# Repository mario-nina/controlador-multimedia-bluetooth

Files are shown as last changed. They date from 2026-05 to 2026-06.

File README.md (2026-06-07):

# Controlador Multimedia Bluetooth






Controlador multimedia inalámbrico portátil basado en ESP32 que permite gestionar la reproducción de audio en una computadora mediante comunicación Bluetooth.

---

## Tabla de contenidos

- [Descripción](#descripción)
- [Características](#características)
- [Requisitos](#requisitos)
- [Instalación](#instalación)
- [Uso](#uso)
- [Estructura del proyecto](#estructura-del-proyecto)
- [Hardware](#hardware)
- [Firmware](#firmware)
- [Documentación](#documentación)
- [Versionado](#versionado)
- [Licencia](#licencia)
- [Autor](#autor)

---

## Descripción

El sistema permite controlar remotamente la reproducción multimedia de una laptop sin requerir interacción física directa con la misma. Comunica mediante protocolo Bluetooth HID, lo que garantiza compatibilidad nativa con el sistema operativo sin necesidad de software adicional.

Desarrollado como proyecto de la materia Sistemas Embebidos II de la carrera de Ingeniería Mecatrónica en la Universidad Católica Boliviana.

---

## Características

- Control de reproducción: Play/Pause
- Navegación entre pistas: Siguiente y Anterior
- Control de volumen: Incremento y Decremento
- Silenciamiento: Mute/Unmute
- Comunicación inalámbrica mediante Bluetooth HID
- Operación autónoma mediante batería Li-ion recargable
- Indicadores visuales de estado de conexión y batería
- Gestión energética con modem sleep y escalado dinámico de frecuencia CPU

---

## Requisitos

### Hardware

| Componente | Especificación |
|---|---|
| Microcontrolador | ESP32 WROOM-32 (DevKit 30 pines) |
| Batería | Li-ion 18650 3.7V 2600mAh |
| Módulo de carga | TP4056 USB-C con protección |
| Boost converter | MT3608 |
| Regulador | AMS1117-3.3V |
| Encoder rotativo | Alps EC11 |
| Botones | 3 pulsadores táctiles |
| Indicadores | LED azul (Bluetooth — GPIO32), LED rojo (batería — GPIO33) |

### Software

| Herramienta | Versión |
|---|---|
| ESP-IDF | v6.0.1 |
| KiCad | 8.0 |
| Sistema operativo | Ubuntu 24.04 LTS |
| Compilador | xtensa-esp-elf-gcc 15.2.0 |
| Python | 3.12.3 |
| CMake | 3.28.3 |
| Git | 2.43.0 |

---

## Instalación

### Configuración del entorno

1. Instalar ESP-IDF v6.0.1 siguiendo la [documentación oficial](https://docs.espressif.com/projects/esp-idf/en/stable/esp32/get-started/index.html).

2. Clonar el repositorio:
```bash
git clone git@github.com:mario-nina/controlador-multimedia-bluetooth.git
cd controlador-multimedia-bluetooth
```

3. Activar el entorno ESP-IDF:
```bash
get_idf
```

4. Configurar el chip objetivo:
```bash
cd firmware
idf.py set-target esp32
```

5. Compilar el firmware:
```bash
idf.py build
```

6. Flashear el ESP32:
```bash
idf.py flash monitor
```

---

## Uso

1. Encender el dispositivo.
2. En la laptop, activar Bluetooth y buscar dispositivos disponibles.
3. Emparejar con el dispositivo **"Controlador Multimedia"**.
4. Una vez conectado, usar los controles:

| Control | Función |
|---|---|
| Encoder — girar derecha | Subir volumen |
| Encoder — girar izquierda | Bajar volumen |
| Encoder — presionar | Play/Pause |
| Botón 1 | Siguiente pista |
| Botón 2 | Pista anterior |
| Botón 3 | Mute/Unmute |

### Indicadores visuales

| LED | Estado | Significado |
|-----|---|---|
| Azul | Parpadeo rápido | Sin conexión BLE — advertising |
| Azul | Apagado | Conexión BLE activa |
| Rojo | Apagado | Batería OK (>= 3400mV) |
| Rojo | Parpadeo lento | Batería baja (< 3400mV) |
| Rojo | Parpadeo rápido | Batería crítica (< 3200mV) |

---

## Estructura del proyecto
controlador-multimedia-bluetooth/
├── firmware/                          # Código fuente del firmware (ESP-IDF)
│   ├── main/                          # Punto de entrada de la aplicación
│   │   └── firmware.c
│   └── components/                    # Módulos independientes
│       ├── common/                    # Configuración global del sistema
│       │   └── include/
│       │       ├── config.h           # Constantes de configuración del sistema
│       │       └── pines.h            # Mapa de asignación de pines GPIO
│       ├── comunicacion_bt/           # Stack NimBLE + perfil HID Consumer Control
│       ├── control_leds/              # Patrones de LEDs via esp_timer
│       ├── driver_entrada/            # Botones (ISR) + encoder rotativo (PCNT)
│       └── gestion_energia/           # Monitoreo ADC batería + modem sleep
├── hardware/                          # Archivos de diseño de hardware
│   ├── kicad/                         # Proyecto KiCad (esquemático + PCB)
│   ├── exportaciones/                 # Archivos exportados desde KiCad
│   │   ├── esquematico/               # PDF y SVG del esquemático
│   │   ├── gerbers/                   # Archivos Gerber para fabricación
│   │   └── step/                      # Modelos 3D de la carcasa
│   └── pines.md                       # Asignación de pines con justificación técnica
├── docs/                              # Documentación técnica
│   ├── memoria_tecnica/               # Memoria técnica del proyecto (entrega académica)
│   ├── diseno_pcb.md                  # Decisiones de diseño PCB con justificación
│   ├── manual_usuario/                # Manual de usuario
│   └── lista_materiales/             # Lista de materiales con especificaciones y costos
├── test/                              # Pruebas y validación
│   └── resultados/                    # Resultados de pruebas documentadas
├── CHANGELOG.md
├── CONTRIBUTING.md
├── CONVENTIONS.md
├── LICENSE
├── ROADMAP.md
└── README.md

---

## Hardware

El sistema se compone de cuatro subsistemas principales:

- **Interfaz de usuario** — encoder rotativo Alps EC11 y tres botones táctiles para generación de comandos
- **Microcontrolador** — ESP32 WROOM-32 como unidad central de procesamiento
- **Sistema de alimentación** — batería Li-ion 18650 → TP4056 (carga USB-C) → MT3608 (boost) → AMS1117-3.3V
- **Indicadores de estado** — LED azul (GPIO32) para Bluetooth y LED rojo (GPIO33) para batería

Los archivos de diseño se encuentran en `hardware/kicad/` y las exportaciones en `hardware/exportaciones/`.

---

## Firmware

Desarrollado en C mediante ESP-IDF v6.0.1 con arquitectura basada en FreeRTOS.

Separación de responsabilidades en componentes independientes:

| Componente | Responsabilidad |
|---|---|
| `common` | Configuración global — `config.h` y `pines.h` |
| `driver_entrada` | Lectura de botones (ISR + debounce) y encoder (PCNT) |
| `comunicacion_bt` | Stack NimBLE, advertising, perfil HID Consumer Control |
| `control_leds` | Patrones de iluminación via esp_timer |
| `gestion_energia` | Monitoreo ADC batería y modem sleep via esp_pm |

---

## Documentación

| Documento | Ubicación | Descripción |
|---|---|---|
| Asignación de pines | `hardware/pines.md` | Pines GPIO con justificación técnica y restricciones del ESP32 |
| Decisiones de diseño PCB | `docs/diseno_pcb.md` | Criterios técnicos aplicados en el diseño del PCB |
| Memoria técnica | `docs/memoria_tecnica/` | Documento académico de descripción del proyecto |
| Historial de cambios | `CHANGELOG.md` | Registro de cambios por versión |
| Roadmap | `ROADMAP.md` | Estado actual y tareas pendientes por área |

---

## Versionado

Este proyecto usa [SemVer](https://semver.org/lang/es/) para el versionado.
El historial de cambios se documenta en [CHANGELOG.md](CHANGELOG.md).

---

## Licencia

Este proyecto está bajo la licencia MIT. Ver [LICENSE](LICENSE) para más detalles.

---

## Autor

**Mario Nina**
Ingeniería Mecatrónica — Universidad Católica Boliviana
GitHub: [@mario-nina](https://github.com/mario-nina)

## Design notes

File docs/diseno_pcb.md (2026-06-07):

# Decisiones de diseño PCB — Controlador Multimedia Bluetooth v1.0

Registro de decisiones técnicas tomadas durante el diseño del PCB con su
justificación. Sirve como referencia para entender el diseño actual y como
base para revisiones futuras.

---

## Anchos de pista

Base de cálculo: norma IPC-2221 con elevación de temperatura máxima de 10°C
y espesor de cobre de 35µm (1oz).

| Red | Corriente | Teórico IPC-2221 | Valor final |
|-----|---|---|---|
| Señales GPIO | 10mA | 0.02mm | 0.8mm |
| VCC 3.3V | 260mA | 0.08mm | 0.8mm |
| VBAT, BAT_P, OUT_P, BOOST_P, PWR_SW | 1A | 0.35mm | 1.0mm |
| VBAT_ADC | <1mA | 0.02mm | 0.8mm |
| GND | — | — | Plano completo |

`VBAT_ADC` se clasificó como señal (0.8mm) a pesar del nombre — la corriente
es de microamperios al ser solo lectura ADC.

---

## Clearance

Valor definido: **0.5mm** en todas las clases de red.

---

## Clases de red

| Clase | Ancho | Clearance | Redes |
|---|---|---|---|
| Default | 0.8mm | 0.5mm | Señales GPIO, LEDs, encoder |
| Power | 1.0mm | 0.5mm | VBAT, BAT_P, OUT_P, BOOST_P, PWR_SW, VCC |

---

## Plano de GND

Se implementó plano de cobre GND en F.Cu en lugar de pistas individuales.

Configuración:
- Fill type: Solid fill
- Clearance: 0.5mm
- Minimum width: 0.5mm
- Pad connections: Thermal reliefs
- Remove islands: Always

El pad C del encoder SW4 usa Solid en lugar de Thermal reliefs por falta de
espacio físico para los spokes.

---

## Capacitores de desacople

**Decisión: no se agregan.**

Justificación:
- Los módulos TP4056, MT3608 y AMS1117 incluyen capacitores en su propia PCB
- El ESP32 WROOM-32 tiene capacitores internos en el módulo
- El circuito opera a baja frecuencia — botones, encoder, LEDs — sin cargas
  con cambios abruptos de corriente

Consideración para revisiones futuras: agregar capacitores de desacople en
la línea VCC si se presentan resets esporádicos.

---

## Diodo TVS

**Decisión: no se agrega en esta revisión.**

Justificación: el componente correcto para protección de la línea USB de 5V
no estaba disponible en proveedores locales al momento del diseño. El P6KE27A
disponible tiene voltaje de ruptura de 25.7V — incompatible con 5V.

Mejora pendiente para revisiones futuras.

---

## Keepout zone de antena ESP32

**Decisión: no se define keepout formal.**

Justificación: el ESP32 WROOM-32 se representó mediante headers J1/J2 en lugar
de footprint de módulo completo, lo que impide ubicar con precisión la zona de
antena en el layout.

Consideración de montaje: orientar el ESP32 con la antena hacia el borde de
la placa para minimizar impacto en alcance BLE.

---

## Distribución de componentes

Criterio principal: ergonomía de uso vertical con una mano.

| Zona | Componentes |
|---|---|
| Superior | Encoder y botones |
| Media | ESP32 con headers J1/J2 |
| Inferior | Cadena de potencia: TP4056 → MT3608 → AMS1117, conector batería |

---

## Teardrops

Activados con valores por defecto de KiCad en todos los pads THT y SMD para
reducir el riesgo de corte en la unión entre pista y pad durante el grabado.

---

*Proyecto: Controlador Multimedia Bluetooth*
*Universidad Católica Boliviana — Ingeniería Mecatrónica*

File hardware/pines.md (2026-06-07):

# Asignación de pines — ESP32 WROOM-32 DevKit 30 pines

Documento de referencia para el proyecto **Controlador Multimedia Bluetooth**.
Registra los pines utilizados, su justificación técnica, restricciones del
microcontrolador, y criterios para selección de pines alternativos.

Última actualización: junio 2026

---

## Tabla de contenidos

- [Pines utilizados](#pines-utilizados)
- [Restricciones del ESP32 WROOM-32](#restricciones-del-esp32-wroom-32)
- [Pines disponibles para expansión](#pines-disponibles-para-expansión)
- [Criterios de selección](#criterios-de-selección)
- [Referencia de periféricos internos](#referencia-de-periféricos-internos)

---

## Pines utilizados

### Indicadores visuales

| GPIO | Pin DevKit | Función | Periférico | Dirección | Pull | Estado |
|---|---|---|---|---|---|---|
| 32 | D32 | LED azul — estado Bluetooth | GPIO | Salida | — | ✓ Validado |
| 33 | D33 | LED rojo — estado batería | GPIO | Salida | — | ✓ Validado |

**Notas:**
- Resistencia de 1kΩ en serie con cada LED hacia GND.
- GPIO32 y GPIO33 pertenecen a ADC1 — compatibles con BLE activo.
- Pines reasignados desde GPIO26/GPIO27 para facilitar ruteo del PCB.
- Ambos pines validados físicamente.

**Pines alternativos aceptables para LEDs:** GPIO4, GPIO5\*, GPIO13, GPIO14, GPIO15\*, GPIO16, GPIO17.

---

### Botones

| GPIO | Pin DevKit | Función | Periférico | Dirección | Pull | Estado |
|---|---|---|---|---|---|---|
| 22 | D22 | Botón Next | GPIO + ISR | Entrada | Pull-up interno | ✓ Validado |
| 23 | D23 | Botón Previous | GPIO + ISR | Entrada | Pull-up interno | ✓ Validado |
| 25 | D25 | Botón Mute/Unmute | GPIO + ISR | Entrada | Pull-up interno | ✓ Validado |

**Notas:**
- Configurados con `GPIO_INTR_NEGEDGE` — interrupción en flanco de bajada.
- Pull-up interno del ESP32 (~45kΩ) es suficiente para pulsadores táctiles. No se requieren resistencias externas.
- Debouncing implementado por software mediante timestamp con umbral de 150ms.
- Los tres pines validados físicamente sin rebotes.

**Pines alternativos aceptables para botones:** cualquier GPIO de propósito general con soporte de interrupción: GPIO4, GPIO13, GPIO14, GPIO16, GPIO17. Evitar GPIO34-39 para botones porque son solo entrada y algunos no tienen pull-up interno.

---

### Encoder rotativo EC11

| GPIO | Pin DevKit | Función | Periférico | Dirección | Pull | Estado |
|---|---|---|---|---|---|---|
| 18 | D18 | Encoder CLK (canal A) | PCNT canal A edge | Entrada | Pull-up manual | ✓ Validado |
| 19 | D19 | Encoder DT (canal B) | PCNT canal A level / canal B edge | Entrada | Pull-up manual | ✓ Validado |
| 21 | D21 | Encoder SW (pulsador) | GPIO + ISR | Entrada | Pull-up interno | ✓ Validado |

**Notas:**
- GPIO18 y GPIO19 son los pines recomendados para PCNT porque soportan todos los periféricos de alta velocidad.
- El periférico PCNT no configura pull-ups automáticamente — se aplican manualmente con `gpio_set_pull_mode()`.
- Filtro de glitches del PCNT configurado en 10µs (`max_glitch_ns = 10000`) para suprimir ruido mecánico del EC11.
- Watch points en ±4 — genera un evento por cada detente físico completo del EC11 (4 pulsos de cuadratura).
- Dirección CW → `EVT_VOL_SUBIR`, CCW → `EVT_VOL_BAJAR`. Validado físicamente.
- Debouncing de dirección en callback PCNT: cambios de dirección en menos de 50ms se descartan.

**Pines alternativos aceptables para PCNT:** GPIO18/GPIO19 son la primera opción. Alternativas: GPIO4/GPIO13. Evitar GPIO34-39 para CLK/DT porque son solo entrada y el PCNT necesita pines bidireccionales para algunos modos.

---

### Sistema de alimentación

| GPIO | Pin DevKit | Función | Periférico | Dirección | Pull | Estado |
|---|---|---|---|---|---|---|
| 34 | D34 | ADC batería (divisor resistivo) | ADC1 canal 6 | Entrada analógica | — | ✓ Validado |

**Notas:**
- GPIO34 es entrada exclusiva — no puede configurarse como salida.
- Usar obligatoriamente ADC1 (GPIO32-GPIO39) para lectura de batería. ADC2 es incompatible con BLE activo.
- Divisor resistivo: 100kΩ desde VBAT+ → nodo → 100kΩ → GND. El nodo central conecta a GPIO34.
- Atenuación: `ADC_ATTEN_DB_12` para rango 0–3.3V.

**Pines alternativos aceptables para ADC batería:** GPIO35, GPIO36, GPIO39 — todos pertenecen a ADC1 y son compatibles con BLE activo. Son solo entrada, lo cual es adecuado para ADC.

---

## Restricciones del ESP32 WROOM-32

### Pines reservados — nunca usar

| GPIO | Razón |
|---|---|
| GPIO6 | Bus SPI flash interno (CLK) |
| GPIO7 | Bus SPI flash interno (SD0/MISO) |
| GPIO8 | Bus SPI flash interno (SD1/MOSI) |
| GPIO9 | Bus SPI flash interno (SD2) |
| GPIO10 | Bus SPI flash interno (SD3) |
| GPIO11 | Bus SPI flash interno (CMD) |

Usar cualquiera de estos pines causa comportamiento indefinido o fallo de arranque del chip.

---

### Pines de strapping — precaución en boot

| GPIO | Función de strapping | Estado seguro en operación |
|---|---|---|
| GPIO0 | Boot mode (LOW = flash, HIGH = normal) | Libre tras arranque, evitar cargas que lo mantengan en LOW |
| GPIO2 | Debe estar en LOW o flotante durante flash | Libre tras arranque |
| GPIO5 | SDIO timing | Libre tras arranque, tiene pull-up interno |
| GPIO12 | VDD_SDIO voltage (HIGH = 1.8V, LOW = 3.3V) | Mantener en LOW o flotante — crítico para alimentación |
| GPIO15 | MTDO / silencia mensajes de boot en LOW | Libre tras arranque |

**Regla práctica:** estos pines pueden usarse en operación normal, pero no conectar resistencias de pull-down en GPIO12 ni elementos que fuercen GPIO0 a LOW permanentemente.

---

### ADC2 — incompatible con BLE/WiFi

Los siguientes pines pertenecen a ADC2 y **no pueden usarse para lectura analógica mientras BLE esté activo:**

GPIO0, GPIO2, GPIO4, GPIO12, GPIO13, GPIO14, GPIO15, GPIO25, GPIO26, GPIO27.

Para lectura analógica con BLE activo, usar exclusivamente ADC1: GPIO32-GPIO39.

---

### GPIO34-GPIO39 — solo entrada

| GPIO | Nota |
|---|---|
| GPIO34 | Solo entrada, sin pull-up/pull-down interno |
| GPIO35 | Solo entrada, sin pull-up/pull-down interno |
| GPIO36 (VP) | Solo entrada, sin pull-up/pull-down interno |
| GPIO39 (VN) | Solo entrada, sin pull-up/pull-down interno |

No pueden configurarse como salida. Adecuados para ADC1 y señales de entrada que no requieran pull-up interno.

---

## Pines disponibles para expansión

Pines no utilizados en el diseño actual, libres para funciones futuras:

| GPIO | Observaciones |
|---|---|
| GPIO4 | Propósito general, soporta ADC2 (no usar con BLE), touch |
| GPIO13 | Propósito general, soporta ADC2 (no usar con BLE), touch |
| GPIO14 | Propósito general, soporta ADC2 (no usar con BLE), touch |
| GPIO16 | Propósito general, sin restricciones relevantes |
| GPIO17 | Propósito general, sin restricciones relevantes |
| GPIO26 | Propósito general, ADC2 (no usar con BLE) |
| GPIO27 | Propósito general, ADC2 (no usar con BLE) |
| GPIO35 | Solo entrada, ADC1 canal 7 |
| GPIO36 (VP) | Solo entrada, ADC1 canal 0 |
| GPIO39 (VN) | Solo entrada, ADC1 canal 3 |

GPIO1 (TX0) y GPIO3 (RX0) están en uso por la UART de consola/monitor serie durante desarrollo. No usar para funciones de aplicación.

---

## Criterios de selección

Los pines del proyecto se seleccionaron siguiendo estos criterios en orden de prioridad:

1. **Compatibilidad con BLE activo** — evitar ADC2 para señales analógicas; verificar que los pines no interfieren con el stack Bluetooth.

2. **Periférico hardware dedicado** — preferir pines que permiten usar periféricos de hardware (PCNT para encoder, ADC1 para batería) en lugar de implementaciones por software, para mayor precisión y menor carga del CPU.

3. **Ausencia de funciones de strapping** — evitar pines que afectan el comportamiento de arranque del chip para simplificar el diseño del PCB.

4. **Facilidad de ruteo en PCB** — agrupar pines por subsistema para minimizar cruces de pistas y simplificar el layout.

5. **Validación física incremental** — cada pin se confirmó funcionando en hardware físico antes de comprometerse en el esquemático KiCad.

---

## Referencia de periféricos internos

| Periférico | Usado para | Pines asignados |
|---|---|---|
| GPIO + ISR | Botones y pulsador encoder | GPIO21, GPIO22, GPIO23, GPIO25 |
| GPIO salida | LEDs indicadores | GPIO32, GPIO33 |
| PCNT unidad 0 | Decodificación cuadratura encoder | GPIO18 (CLK), GPIO19 (DT) |
| ADC1 canal 6 | Monitoreo voltaje batería | GPIO34 |
| UART0 | Monitor serie (desarrollo) | GPIO1 (TX), GPIO3 (RX) |

---

*Proyecto: Controlador Multimedia Bluetooth — Sistemas Embebidos II*
*Universidad Católica Boliviana — Ingeniería Mecatrónica*

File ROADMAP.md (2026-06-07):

# Roadmap

Plan de desarrollo del controlador multimedia inalámbrico Bluetooth basado en ESP32.
Refleja el estado actual del proyecto y las tareas pendientes por área de trabajo.

---

## Estado general

| Área | Estado |
|---|---|
| Firmware | ✓ Completo |
| Hardware — esquemático | ✓ Completo |
| Hardware — PCB | ✓ Completo |
| Hardware — diseño 3D | ✓ Completo |
| Pruebas | En curso |
| Documentación | En curso |

---

## Firmware

| Tarea | Estado |
|---|---|
| Proyecto base ESP-IDF y estructura de componentes | ✓ |
| Driver de botones con debouncing por timestamp | ✓ |
| Driver de encoder rotativo EC11 mediante PCNT | ✓ |
| Control de LEDs con patrones via esp_timer | ✓ |
| Stack NimBLE con advertising y callbacks de conexión | ✓ |
| Perfil HID Consumer Control — 6 comandos multimedia | ✓ |
| Máquina de estados del sistema con mutex FreeRTOS | ✓ |
| Gestión de energía — ADC batería con promediado y calibración | ✓ |
| Gestión de energía — modem sleep via esp_pm | ✓ |
| Arquitectura de componentes refactorizada — config.h, buenas prácticas | ✓ |
| Validación funcional con fuente de voltaje | ✓ |
| Validación funcional con batería real | ✓ |

---

## Hardware

### Esquemático

| Tarea | Estado |
|---|---|
| Cadena de potencia — batería → TP4056 → MT3608 → AMS1117-3.3V | ✓ |
| Interfaz de usuario — encoder EC11 y botones | ✓ |
| Indicadores visuales — LEDs con resistencias | ✓ |
| Divisor resistivo para monitoreo de batería | ✓ |
| ERC sin errores | ✓ |
| Huellas asignadas a todos los componentes | ✓ |
| Modelos 3D asignados a todos los componentes | ✓ |
| Exportación PDF del esquemático | ✓ |

### PCB

| Tarea | Estado |
|---|---|
| Importar netlist desde esquemático | ✓ |
| Placement de componentes | ✓ |
| Ruteo de señales | ✓ |
| Plano de GND | ✓ |
| Silkscreen con etiquetas y versión | ✓ |
| DRC sin errores | ✓ |
| Exportación de Gerbers | ✓ |
| Fabricación física | ✓ |

### Diseño 3D

| Tarea | Estado |
|---|---|
| Modelo de carcasa | ✓ |
| Verificación de medidas contra PCB | ✓ |
| Verificación de acceso a conectores USB y botones | ✓ |
| Exportación STEP | ✓ |
| Impresión 3D | Pendiente |

---

## Pruebas

| Prueba | Estado |
|---|---|
| Integración completa — 6 comandos end-to-end con Spotify | ✓ |
| Protocolo de pruebas formales definido | ✓ |
| Prueba 1 — Alcance BLE | Pendiente |
| Prueba 2 — Latencia | Pendiente |
| Prueba 3 — Autonomía de batería | Pendiente |
| Prueba 4 — Confiabilidad | Pendiente |
| Prueba 5 — Compatibilidad | Pendiente |

---

## Documentación

| Tarea | Estado |
|---|---|
| README con descripción, requisitos e instrucciones | ✓ |
| Asignación de pines con justificación técnica | ✓ |
| Decisiones de diseño PCB | ✓ |
| Memoria técnica del proyecto (entrega académica) | ✓ |
| Lista de materiales con especificaciones y costos | ✓ |
| Manual de usuario | ✓ |
| Documentación técnica del sistema | Pendiente |

---

## Hitos

| Hito | Descripción | Estado |
|---|---|---|
| MVP firmware | 6 comandos funcionando end-to-end desde hardware hasta Ubuntu via BLE HID | ✓ Logrado |
| Esquemático completo | ERC sin errores, huellas y modelos 3D asignados | ✓ Logrado |
| PCB fabricada | DRC sin errores, Gerbers exportados, PCB física lista | ✓ Logrado |
| Sistema validado | Pruebas formales documentadas con batería real | Pendiente |
| Entrega final | Pruebas formales y documentación técnica completa | Pendiente |

---

*Proyecto académico — Sistemas Embebidos II · Ingeniería Mecatrónica · UCB*

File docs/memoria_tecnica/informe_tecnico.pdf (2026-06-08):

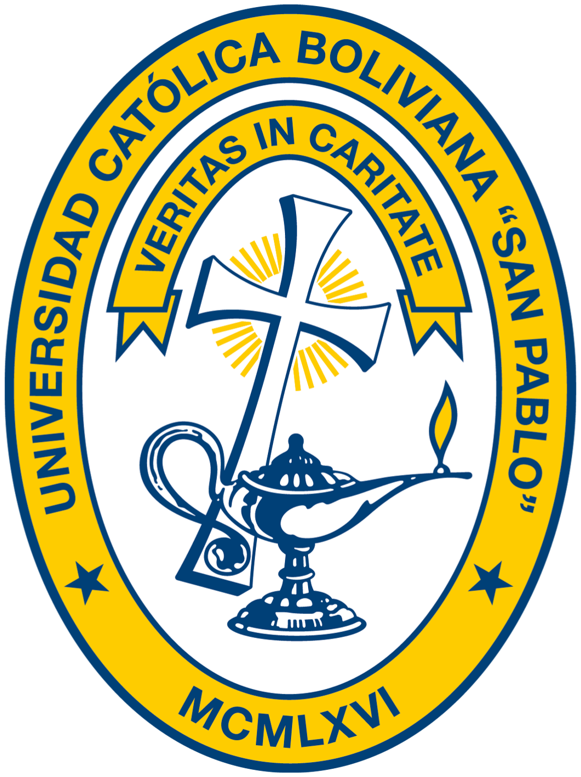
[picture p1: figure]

Universidad Catolica Boliviana ”San Pablo” ´

Departamento de Ciencias de la Tecnología e Innovacion´

Ingeniería Mecatronica ´

# Controlador Multimedia Inalámbrico Bluetooth basado en ESP32

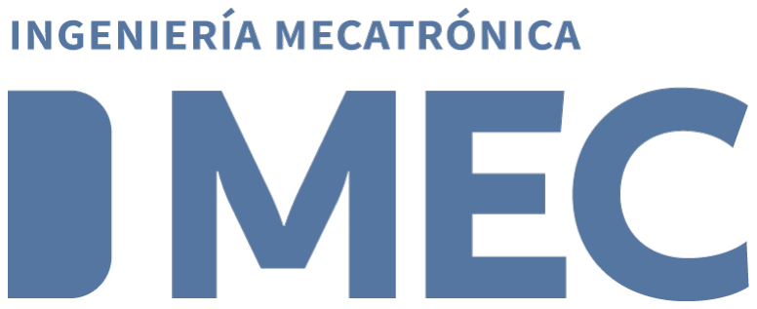
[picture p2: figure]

### Materia: Sistemas Embebidos II Estudiante(s): Mario Alberto Nina Gallo Docente: Ing. Elmer Alan Cornejo Quito Semestre: 1/2026

### Bolivia, 8 de junio de 2026

## Índice

1. Introducción | 1
2. Marco teórico | 2
3. Diseño e implementación del hardware | 3
4. Diseño e implementación del firmware | 5
5. Resultados y validación | 7
6. Conclusiones | 8
Referencias Bibliográficas | 10

## Índice de figuras

1. | Diagrama en bloques del sistema | | 4

## 1. Introducción

El presente informe documenta el diseño, implementación y validación de un controlador multimedia inalámbrico portátil basado en el microcontrolador ESP32 de Espressif Systems. El sistema permite gestionar la reproducción de contenido de audio en una computadora portátil sin requerir interacción física directa con la misma, mediante comunicación inalámbrica Bluetooth.

### 1.1. Contexto y motivación

El control remoto de reproducción multimedia es una necesidad frecuente en contextos donde el usuario se encuentra en posición de descanso o realizando actividades que dificultan el acceso físico al dispositivo de reproducción. Las soluciones comerciales existentes presentan limitaciones significativas: los controles infrarrojos requieren línea de vista directa y receptores dedicados; las soluciones propietarias están limitadas a ecosistemas cerrados; y las alternativas de radiofrecuencia genérica requieren dongles USB que ocupan puertos y limitan la portabilidad del sistema.

Este proyecto aborda dicha problemática mediante el desarrollo de un dispositivo que implementa el protocolo Bluetooth Human Interface Device (HID), garantizando compatibilidad nativa con el sistema operativo sin necesidad de controladores o software adicional.

### 1.2. Objetivos

Objetivo general: Diseñar e implementar un controlador multimedia inalámbrico portátil basado en microcontrolador de la familia ESP32 que permita gestión remota de reproducción de audio en computadora mediante comunicación Bluetooth, con operación autónoma mediante batería recargable.

Objetivos específicos:

1. Implementar circuito electrónico en PCB basado en microcontrolador ESP32, integrando sistema de alimentación con batería recargable y circuito de carga con protecciones.
2. Desarrollar firmware en C mediante ESP-IDF que gestione comunicación Bluetooth y procesamiento de comandos multimedia: Play/Pause, Next, Previous, volumen, y Mute/Unmute.
3. Establecer comunicación inalámbrica Bluetooth con sistema operativo Linux para transmisión de comandos multimedia.
4. Implementar interfaz de usuario que permita activación diferenciable de funciones, con retroalimentación visual de estado operativo.

5. Validar funcionalmente el sistema mediante pruebas de alcance, autonomía y confiabilidad de transmisión.

## 2. Marco teórico

### 2.1. Bluetooth Low Energy y perfil HID

Bluetooth Low Energy (BLE) es una tecnología de comunicación inalámbrica diseñada para operar en la banda ISM de 2.4 GHz con consumo de energía significativamente reducido respecto a Bluetooth clásico (Bluetooth Special Interest Group, 2023). Opera mediante 40 canales de 2 MHz con salto de frecuencia adaptativo, ofreciendo un rango típico de hasta 50 metros en condiciones favorables.

El perfil HID over GATT (HoGP) es una adaptación del protocolo USB HID para operar sobre BLE mediante el Generic Attribute Profile (GATT) (Bluetooth Special Interest Group, 2011). Este perfil define cómo un dispositivo BLE puede exponer servicios HID a un host, permitiendo que el sistema operativo lo reconozca como un dispositivo de entrada estándar sin necesidad de controladores adicionales. El perfil requiere la implementación de tres servicios GATT: el servicio HID (UUID 0x1812), el servicio de información del dispositivo (UUID 0x180A), y el servicio de batería (UUID 0x180F).

Los comandos multimedia se transmiten mediante la página de uso Consumer Control (Usage Page 0x0C) del estándar USB HID Usage Tables (USB Implementers Forum, 2023). Cada comando se identifica por un código de uso de 16 bits: Play/Pause (0x00CD), Next Track (0x00B5), Previous Track (0x00B6), Volume Increment (0x00E9), Volume Decrement (0x00EA), y Mute (0x00E2).

### 2.2. ESP32 y ESP-IDF

El ESP32 es un sistema en chip (SoC) de Espressif Systems que integra un procesador Xtensa LX6 de doble núcleo a 240 MHz, memoria RAM de 520 KB, y controladores de radio para WiFi 802.11 b/g/n y Bluetooth 4.2/5.0 (Espressif Systems, 2024). Su arquitectura dual-core permite ejecutar el stack Bluetooth en un núcleo mientras el firmware de aplicación opera en el otro, evitando interferencias entre ambos.

ESP-IDF (Espressif IoT Development Framework) es el framework oficial de desarrollo para los SoCs de Espressif (Espressif Systems, 2026). Proporciona una capa de abstracción sobre el hardware, drivers de periféricos, y componentes de sistema incluyendo FreeRTOS, NVS (Non-Volatile Storage), y gestión de energía mediante esp pm.

### 2.3. NimBLE

NimBLE es un stack Bluetooth Low Energy de código abierto desarrollado por el proyecto Apache Mynewt (Apache Software Foundation, 2025). Es el stack BLE integrado en ESP-IDF y se caracteriza por su reducida huella de memoria respecto al stack clásico de Espressif, su soporte completo del rol de periférico BLE, y su compatibilidad con perfiles GATT estándar. NimBLE implementa todas las capas del stack BLE: capa física, enlace, L2CAP, ATT, GATT, GAP y el gestor de seguridad (SM).

### 2.4. FreeRTOS

FreeRTOS es un sistema operativo de tiempo real diseñado para microcontroladores, integrado en ESP-IDF (Real Time Engineers Ltd., 2016). Proporciona primitivas de sincronización y comunicación entre tareas, incluyendo colas (queues), semáforos y mutex. En este proyecto se utiliza para gestionar la comunicación entre el driver de entrada y la tarea de procesamiento de comandos, así como para proteger el acceso concurrente al estado del sistema desde múltiples núcleos del ESP32.

## 3. Diseño e implementación del hardware

### 3.1. Arquitectura del sistema

El sistema se compone de dos elementos principales: el controlador portátil basado en ESP32 y la computadora objetivo. La comunicación entre ambos se establece mediante protocolo Bluetooth BLE HID. El controlador integra cuatro subsistemas: interfaz de usuario, microcontrolador ESP32, sistema de alimentación e indicadores de estado, cuya interacción se ilustra en la figura 1.

### 3.2. Cadena de alimentación

El sistema de alimentación implementa una cadena de conversión de energía que parte de una celda Li-ion 18650 de 3.7V y 2600 mAh. El módulo TP4056 gestiona la carga de la batería mediante conexión USB-C, incorporando protección contra sobrecarga, sobredescarga y cortocircuito. Dado que el voltaje nominal de la batería (3.7V) puede variar entre 3.0V y 4.2V durante el ciclo de carga y descarga, se incorporó un boost converter MT3608 para elevar y estabilizar el voltaje a 5V. Finalmente, el regulador AMS1117-3.3V reduce el voltaje a los 3.3V requeridos por el ESP32 y los demás componentes del sistema.

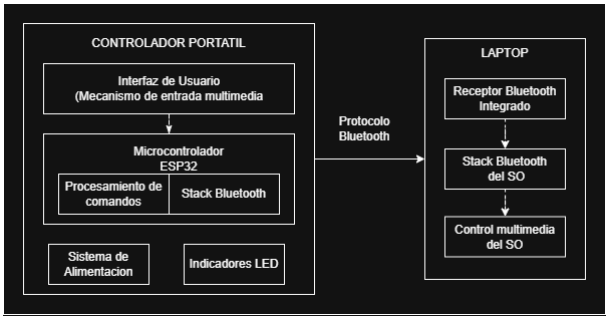
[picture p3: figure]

Figura 1: Diagrama en bloques del sistema.

### 3.3. Interfaz de usuario

La interfaz de usuario integra un encoder rotativo Alps EC11 y tres pulsadores táctiles. El encoder permite control de volumen mediante giro (CW para incremento, CCW para decremento) y Play/Pause mediante pulsación de su eje. Los tres botones activan las funciones de siguiente pista, pista anterior y Mute/Unmute respectivamente. Dos LEDs proveen retroalimentación visual: el LED azul indica el estado de la conexión Bluetooth y el LED rojo indica el nivel de batería.

### 3.4. Diseño del PCB

El PCB se diseñó en KiCad 8.0 como una placa de una capa de 70×100 mm fabricada mediante transferencia térmica sobre baquelita. Los anchos de pista se determinaron mediante la norma IPC-2221, resultando en 0.8 mm para señales y 1.0 mm para líneas de potencia, con un clearance mínimo de 0.5 mm adecuado para el proceso de fabricación casero. Se implementó un plano de cobre completo en la cara de cobre para la red GND, reduciendo la resistencia de retorno y simplificando el ruteo. La disposición de componentes sigue un criterio ergonómico vertical: la interfaz de usuario en la zona superior, el ESP32 en la zona media, y la cadena de potencia en la zona inferior.

### 3.5. Asignación de pines

La selección de pines del ESP32 siguió criterios de compatibilidad con BLE activo, disponibilidad de periféricos hardware dedicados, y ausencia de funciones de strapping que pudieran afectar el arranque. Los pines GPIO32 y GPIO33 se asignaron a los LEDs por pertenecer a ADC1, siendo compatibles con BLE activo. Los pines GPIO18 y GPIO19 se asignaron al encoder por su soporte nativo del periférico PCNT. El pin GPIO34 se asignó a la lectura ADC de batería por ser entrada exclusiva perteneciente a ADC1, compatible con BLE activo. Los pines ADC2 se evitaron completamente dado su incompatibilidad con el stack BLE.

## 4. Diseño e implementación del firmware

### 4.1. Arquitectura de componentes

El firmware se desarrolló en lenguaje C utilizando ESP-IDF v6.0.1, estructurado en componentes independientes bajo el sistema de construcción CMake de ESP-IDF. Cada componente encapsula una responsabilidad específica del sistema, siguiendo el principio de separación de responsabilidades.

common: Configuración global del sistema mediante config.h y mapa de pines GPIO mediante pines.h.

driver entrada: Driver de botones con debouncing por timestamp e interrupción GPIO, y driver de encoder rotativo mediante el periférico PCNT con decodificación de cuadratura en hardware.

comunicacion bt: Stack NimBLE con advertising BLE, callbacks de conexión y desconexión, y perfil HID Consumer Control sobre GATT.

control leds: Control de patrones de iluminación LED mediante temporizadores esp timer sin bloqueo de tareas.

gestion energia: Monitoreo periódico de voltaje de batería mediante ADC1 con promediado de muestras y calibración line fitting.

### 4.2. Driver de entrada

El driver de botones configura los GPIOs con pull-up interno e interrupción por flanco descendente (GPIO INTR NEGEDGE). El debouncing se implementa por software mediante comparación de timestamps con esp timer get time(), descartando eventos que ocurren dentro de un intervalo de 150 ms respecto al evento anterior. Este enfoque es más robusto que el debouncing por retardo (vTaskDelay) ya que no bloquea el contexto de la ISR.

El driver de encoder utiliza el periférico PCNT (Pulse Counter) del ESP32 para decodificación de cuadratura en hardware, configurando dos canales para capturar flancos en ambas señales CLK y DT. Los watch points se configuran en ±4 pulsos, lo que corresponde a exactamente un detente físico del EC11, generando un evento de subida o bajada de volumen por cada clic perceptible del encoder. Un filtro de glitches de 10 µs suprime el ruido mecánico del encoder antes de que alcance el contador.

### 4.3. Comunicación Bluetooth HID

El stack NimBLE se inicializa con BLE clásico desactivado para reducir el consumo de memoria flash. El servicio HID se registra en el servidor GATT mediante un descriptor HID que define el formato de reporte Consumer Control: un campo de 16 bits con rango 0x0000 a 0x03FF correspondiente a los códigos de uso de la página Consumer Control del estándar USB HID Usage Tables.

Para cada comando, se envían dos reportes consecutivos mediante notificaciones GATT: el reporte activo con el código de uso correspondiente, seguido obligatoriamente de un reporte de key-up (0x0000). Este segundo reporte es necesario para indicar al host que la tecla fue liberada; sin él, el sistema operativo interpreta una pulsación continua y ejecuta la acción repetidamente.

Al producirse una desconexión, el stack reinicia el advertising de manera inmediata. Dado que el ESP32 opera como periférico BLE, no puede iniciar conexiones — es el host quien debe conectarse al periférico. Este comportamiento es correcto para dispositivos HID: Ubuntu reconoce el dispositivo como de confianza y reconecta automáticamente al detectar el advertising.

### 4.4. Máquina de estados

El sistema implementa una máquina de estados finitos con dos estados operativos:

SYS ADVERTISING: Estado inicial y de espera. El LED azul parpadea rápidamente indicando que el dispositivo está anunciando su presencia mediante BLE advertising.

SYS CONNECTED: Conexión BLE activa. El LED azul se apaga. Los comandos de entrada se procesan y transmiten al host.

El acceso al estado del sistema está protegido mediante un mutex FreeRTOS, dado que el ESP32 es un sistema dual-core donde la tarea NimBLE opera en el núcleo 1 y la tarea de procesamiento de comandos opera en el núcleo 0, existiendo posibilidad de acceso concurrente a la variable de estado.

### 4.5. Gestión de energía

El monitoreo de batería se implementa mediante lectura del ADC1 canal 6 (GPIO34), que mide el voltaje en el punto medio de un divisor resistivo 100kΩ/100kΩ conectado a la batería. El voltaje leído se multiplica por 2 para obtener el voltaje real de la batería. Se promedian 16 muestras consecutivas para reducir el ruido inherente del ADC, y se aplica calibración line fitting de ESP-IDF para obtener valores en milivoltios con mayor precisión.

Se definieron tres niveles de batería: OK (≥ 3400 mV), bajo (¡3400 mV) y crítico (¡3200 mV), con retroalimentación visual correspondiente mediante el LED rojo.

### 4.5.1. Modo de bajo consumo

Durante el desarrollo se evaluó la implementación de light sleep para reducir el consumo energético durante períodos de inactividad. Sin embargo, se determinó que el stack Nim-BLE en la configuración utilizada pierde la conexión BLE activa al entrar en light sleep, dado que el CPU se suspende y no puede mantener los intervalos de conexión requeridos por el protocolo BLE.

Como solución alternativa se implementó modem sleep mediante esp pm configure(), habilitando el escalado dinámico de frecuencia del CPU entre 40 MHz y 160 MHz. Este modo permite al sistema reducir la frecuencia de operación automáticamente cuando las tareas están en espera, sin interrumpir la conexión BLE. Si bien el ahorro energético es menor que el del light sleep, esta solución mantiene la conexión activa en todo momento, lo que es esencial para la experiencia de uso del dispositivo.

## 5. Resultados y validación

### 5.1. Validación funcional

Se realizó una prueba de integración completa con el sistema en hardware físico, validando los seis comandos multimedia con Spotify y YouTube bajo Ubuntu 24.04 LTS. Los resultados se presentan en la tabla 1.

Tabla 1: Resultados de validación de comandos multimedia.
Comando | Control físico | Resultado
Play/Pause | Encoder — presionar | Funciona correctamente
Siguiente pista Botón 1 | Funciona correctamente
Pista anterior | Botón 2 | Funciona correctamente
Subir volumen | Encoder — girar derecha | Funciona correctamente
Bajar volumen Encoder — girar izquierda Funciona correctamente
Mute/Unmute | Botón 3 | Funciona correctamente

### 5.2. Alcance Bluetooth

Se verificó el funcionamiento del dispositivo en condiciones de uso típico dentro de una habitación, con y sin obstáculos entre el controlador y la computadora. El enlace BLE se mantuvo estable en el rango de operación de una habitación grande, cumpliendo el objetivo de permitir control desde ubicaciones de descanso sin necesidad de línea de vista directa.

### 5.3. Autonomía de batería

Con la celda Li-ion 18650 de 2600 mAh completamente cargada, el dispositivo operó durante un mínimo de 4 horas en uso normal, definido como comandos ejecutados aproximadamente cada 5 minutos con el sistema en estado conectado. La sesión de prueba se interrumpió antes del agotamiento de la batería, por lo que la autonomía real podría ser superior.

### 5.4. Latencia

La respuesta del sistema fue evaluada subjetivamente durante las sesiones de uso. El retardo entre la activación de un control y la ejecución de la acción correspondiente en el host fue imperceptible en condiciones normales de operación, consistente con la naturaleza de baja latencia del protocolo BLE HID para comandos discretos.

### 5.5. Análisis de resultados

Los resultados obtenidos validan el cumplimiento de los objetivos planteados. El sistema implementa exitosamente el perfil BLE HID Consumer Control, logrando compatibilidad nativa con Ubuntu 24.04 LTS sin necesidad de software adicional. La autonomía de 4 horas con una celda de 2600 mAh representa una mejora significativa respecto a la batería LiPo de 500 mAh inicialmente contemplada en el diseño.

La decisión de reemplazar light sleep por modem sleep implicó un compromiso entre ahorro energético y continuidad de la conexión BLE. Para un dispositivo HID, mantener la conexión activa es prioritario sobre el máximo ahorro energético, ya que una desconexión requiere intervención del usuario para reconectar. El modem sleep con escalado dinámico de frecuencia CPU provee un balance adecuado para el caso de uso del proyecto.

## 6. Conclusiones

Se diseñó e implementó exitosamente un controlador multimedia inalámbrico portátil basado en el microcontrolador ESP32, cumpliendo los objetivos planteados al inicio del proyecto.

El sistema implementa el perfil Bluetooth HID Consumer Control mediante el stack Nim-BLE sobre ESP-IDF v6.0.1, logrando compatibilidad nativa con Linux sin necesidad de controladores adicionales. Los seis comandos multimedia planteados — Play/Pause, Next, Previous, Volume Up, Volume Down y Mute/Unmute — operan correctamente de extremo a extremo desde el hardware físico hasta el sistema operativo.

El diseño del firmware siguió principios de ingeniería de software embebido: separación de responsabilidades en componentes independientes, centralización de configuración, protección de recursos compartidos mediante primitivas FreeRTOS, y cero números mágicos en el código. Estas decisiones facilitan el mantenimiento y la extensión del sistema.

El proceso de desarrollo evidenció la importancia de la validación física incremental: decisiones como la selección de pines GPIO, la configuración del periférico PCNT para el encoder, y la elección del modo de bajo consumo surgieron de pruebas en hardware real y no pudieron determinarse únicamente por análisis teórico.

Como trabajo futuro se identifican las siguientes líneas de mejora: implementación de light sleep coordinado con el stack BLE para mayor ahorro energético, diseño de PCB multicapa para reducir el tamaño del dispositivo, y extensión de la compatibilidad a sistemas operativos Windows y macOS.

## Referencias Bibliográficas

Apache Software Foundation. (2025). Apache NimBLE — BLE User Guide. Apache Software Foundation. Consultado el 7 de junio de 2026, desde https://mynewt.apache.org/latest/network/
Bluetooth Special Interest Group. (2011). HID over GATT Profile Specification 1.0. Bluetooth SIG. Consultado el 7 de junio de 2026, desde https://www.bluetooth.com/specifications/specs/hid-over-gatt-profile-1-0/
Bluetooth Special Interest Group. (2023). Bluetooth Core Specification 5.4. Bluetooth SIG. Consultado el 7 de junio de 2026, desde https://www.bluetooth.com/specifications/specs/core-specification-5-4/
Espressif Systems. (2024). ESP32 Series Datasheet. Espressif Systems. Consultado el 7 de junio de 2026, desde https : / / www . espressif . com / sites / default / files / documentation/esp32 datasheet en.pdf
Espressif Systems. (2026). ESP-IDF Programming Guide v6.0.1. Espressif Systems. Consultado el 7 de junio de 2026, desde https:// docs. espressif. com/ projects/ esp -idf/en/stable/esp32/index.html
Real Time Engineers Ltd. (2016). FreeRTOS Reference Manual. Real Time Engineers Ltd. Consultado el 7 de junio de 2026, desde https://www.freertos.org/Documentation/ RTOS book.html
USB Implementers Forum. (2023). HID Usage Tables for USB 1.5. USB Implementers Forum. Consultado el 7 de junio de 2026, desde https://usb.org/sites/default/files/hut1 5.pdf

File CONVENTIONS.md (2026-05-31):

# Convenciones del proyecto

## Idioma

- Documentación, comentarios y nombres de variables/funciones: **español**
- Palabras técnicas sin traducción directa (handle, callback, stack, payload, flag): se mantienen en inglés

---

## Estructura de ramas

| Rama | Propósito |
|---|---|
| `main` | Código estable y validado en hardware. Solo recibe merges desde `develop`. |
| `develop` | Integración activa de desarrollo. Base para nuevas ramas de feature. |
| `feature/<nombre>` | Desarrollo de una funcionalidad nueva. Se fusiona en `develop` al completarse. |

**Regla:** nunca hacer push directo a `main`. Todo cambio entra por `develop`.

---

## Mensajes de commit

Formato: `<tipo>: <descripción en imperativo y minúsculas>`

### Tipos válidos

| Tipo | Cuándo usarlo |
|---|---|
| `feat` | Nueva funcionalidad implementada |
| `fix` | Corrección de un error |
| `docs` | Cambios exclusivamente en documentación |
| `test` | Registro de pruebas físicas o de validación |
| `hardware` | Cambios en esquemático, PCB o archivos KiCad |
| `chore` | Configuración, dependencias, `.gitignore`, CMakeLists |
| `refactor` | Reestructuración de código sin cambio de comportamiento |

### Ejemplos correctos

```
feat: implementar perfil HID Consumer Control con reportes BLE
fix: corregir debouncing del encoder en cambios rápidos de dirección
docs: actualizar roadmap con estado real de las fases
test: confirmar GPIO22 GPIO23 GPIO25 sin rebotes en hardware físico
hardware: completar esquemático con cadena de potencia y ERC sin errores
chore: agregar sdkconfig.defaults con configuración NimBLE
refactor: mover nvs_flash_init a app_main
```

---

## Código C

### Nombres

| Elemento | Convención | Ejemplo |
|---|---|---|
| Funciones | `snake_case` con prefijo del módulo | `driver_entrada_init`, `control_leds_set` |
| Variables locales | `snake_case` | `cola_eventos`, `ultimo_tiempo` |
| Variables estáticas de módulo | `snake_case` | `static uint16_t conn_handle` |
| Constantes y macros | `SNAKE_CASE_MAYUSCULAS` | `DEBOUNCE_TIEMPO_US`, `LED_PERIODO_RAPIDO_US` |
| Tipos (`typedef enum/struct`) | `snake_case_t` | `evento_entrada_t`, `sys_state_t` |
| Tags de log ESP-IDF | nombre del módulo en minúsculas | `"driver_entrada"`, `"hid"` |

### Archivos

- Implementación: `<modulo>.c`
- Cabecera pública (API externa): `include/<modulo>.h`
- Cabecera interna (uso solo dentro del componente): `<nombre>.h` en la raíz del componente

### Comentarios

- Solo cuando el **por qué** no es obvio: una restricción oculta, un invariante sutil, un workaround para un bug específico del hardware
- Usar `@brief` en funciones públicas de los headers
- No comentar **qué** hace el código — los nombres de funciones y variables deben ser suficientes
- Los bloques `TODO` se marcan con `/* TODO Fase N: descripción */`

---

## Estructura de componentes ESP-IDF

```
components/<modulo>/
├── CMakeLists.txt
├── <modulo>.c              # Implementación principal
├── <submodulo>.c           # Submódulo interno (si aplica)
├── <submodulo>.h           # Header interno del submódulo
└── include/
    └── <modulo>.h          # API pública del componente
```

---

## Estructura del repositorio

```
controlador-multimedia-bluetooth/
├── firmware/               # Código fuente del firmware (ESP-IDF)
│   ├── main/               # Punto de entrada de la aplicación
│   └── components/         # Módulos independientes
├── hardware/               # Archivos de diseño de hardware
│   ├── controlador_multimedia/   # Proyecto KiCad (fuente)
│   ├── esquematico/              # Exportaciones del esquemático (PDF/SVG)
│   ├── pcb/                      # Exportaciones Gerber
│   ├── diseno_3d/                # Exportaciones STEP
│   └── pines.md                  # Asignación de pines con justificación técnica
├── docs/                   # Documentación técnica
│   ├── memoria_tecnica/    # Memoria técnica del proyecto
│   ├── manual_usuario/     # Manual de usuario
│   └── lista_materiales/   # Lista de materiales con costos
├── test/
│   └── resultados/         # Resultados de pruebas físicas por fase
├── CHANGELOG.md
├── CONVENTIONS.md
├── CONTRIBUTING.md
├── LICENSE
├── README.md
└── ROADMAP.md
```

---

## Flujo de trabajo

1. Crear rama `feature/<nombre>` desde `develop`
2. Desarrollar y validar en hardware físico
3. Actualizar `CHANGELOG.md` y `ROADMAP.md` al completar la fase
4. Crear Pull Request hacia `develop` usando el template de PR
5. Fusionar en `develop`
6. Fusionar `develop` → `main` solo cuando la fase esté completamente validada

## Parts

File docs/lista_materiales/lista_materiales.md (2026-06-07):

cat > docs/lista_materiales/lista_materiales.md << 'EOF'
# Lista de materiales — Controlador Multimedia Bluetooth v1.0

Componentes utilizados en el prototipo físico del proyecto.
Precios relevados a junio 2026 en tiendas de La Paz, Bolivia.

---

## Componentes electrónicos

| # | Componente | Especificación | Cantidad | Precio unitario (Bs) | Subtotal (Bs) | Proveedor |
|---|---|---|---|---|---|---|
| 1 | Microcontrolador | ESP32 WROOM-32 DevKit 30 pines | 1 | 82.00 | 82.00 | EPY Electronic |
| 2 | Módulo de carga | TP4056 USB-C con protección | 1 | 12.00 | 12.00 | EPY Electronic |
| 3 | Boost converter | MT3608 | 1 | 14.00 | 14.00 | EPY Electronic |
| 4 | Regulador de voltaje | AMS1117-3.3V | 1 | 5.00 | 5.00 | Sawers |
| 5 | Batería | Li-ion 18650 3.7V 2600mAh | 1 | 32.00 | 32.00 | Sawers |
| 6 | Portapilas | Portapilas 18650 | 1 | 6.00 | 6.00 | Sawers |
| 7 | Encoder rotativo | Alps EC11 | 1 | 9.00 | 9.00 | Sawers |
| 8 | Pulsador táctil | 6×6mm | 3 | 1.00 | 3.00 | EPY Electronic |
| 9 | Switch | SPDT | 1 | 1.00 | 1.00 | EPY Electronic |
| 10 | LED azul | 5mm | 1 | 0.30 | 0.30 | EPY Electronic |
| 11 | LED rojo | 5mm | 1 | 0.30 | 0.30 | EPY Electronic |
| 12 | Resistencia | 1kΩ 1/4W | 2 | 0.20 | 0.40 | EPY Electronic |
| 13 | Resistencia | 100kΩ 1/4W | 2 | 0.20 | 0.40 | EPY Electronic |
| 14 | Bloque terminal | KF301-2P 2 pines | 1 | — | — | EPY Electronic |

---

## Materiales de fabricación PCB

| # | Material | Especificación | Cantidad | Precio unitario (Bs) | Subtotal (Bs) | Proveedor |
|---|---|---|---|---|---|---|
| 15 | PCB virgen | Baquelita 70×100mm una capa | 1 | 8.50 | 8.50 | Sawers |
| 16 | Regleta macho | 40 pines | 1 | 3.50 | 3.50 | EPY Electronic |
| 17 | Regleta hembra | 40 pines | 1 | 3.50 | 3.50 | EPY Electronic |

---

## Resumen de costos

| Categoría | Subtotal (Bs) |
|---|---|
| Componentes electrónicos | 164.40 |
| Materiales de fabricación PCB | 15.50 |
| **Total** | **179.90** |

> El precio del bloque terminal KF301-2P no fue relevado al momento de la compra.
> Los precios corresponden a junio 2026 y pueden variar.

---

## Proveedores

| Proveedor | Ubicación |
|---|---|
| EPY Electronic | Tarija, Bolivia |
| Sawers | Tarija, Bolivia |

---

*Proyecto: Controlador Multimedia Bluetooth — Sistemas Embebidos II*
*Universidad Católica Boliviana — Ingeniería Mecatrónica*
EOF

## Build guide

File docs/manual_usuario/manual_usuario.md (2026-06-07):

# Manual de usuario — Controlador Multimedia Bluetooth v1.0

Guía de operación del controlador multimedia inalámbrico basado en ESP32.

---

## Descripción del dispositivo

El controlador multimedia permite gestionar la reproducción de audio en una
computadora mediante comunicación Bluetooth, sin requerir interacción física
directa con la misma.

---

## Disposición de controles

De izquierda a derecha:

| Posición | Elemento | Descripción |
|---|---|---|
| 1 | ENC | Encoder rotativo — control de volumen y Play/Pause |
| 2 | PREV | Botón pista anterior |
| 3 | NEXT | Botón siguiente pista |
| 4 | MUTE | Botón Mute/Unmute |
| 5 | 🔵 🔴 | LEDs de estado — Bluetooth y batería |
| 6 | SW | Interruptor de encendido/apagado |
| — | USB | Puerto de carga USB-C — parte inferior derecha |
---

## Encendido y apagado

1. Deslizar el interruptor **SW** hacia la posición de encendido.
2. El LED azul comenzará a parpadear rápidamente — el dispositivo está
   buscando conexión Bluetooth.
3. Para apagar, deslizar el interruptor **SW** hacia la posición de apagado.

---

## Emparejamiento con la computadora

El emparejamiento solo es necesario la primera vez o al cambiar de computadora.

1. Encender el dispositivo — el LED azul parpadeará rápidamente.
2. En la computadora, abrir **Configuración → Bluetooth**.
3. Activar Bluetooth si no está activo.
4. Buscar dispositivos disponibles.
5. Seleccionar **"Controlador Multimedia"** de la lista.
6. Confirmar el emparejamiento cuando se solicite.
7. El LED azul se apagará — la conexión está establecida.

> Para reconectar en sesiones posteriores, encender el dispositivo y activar
> el Bluetooth de la computadora. La reconexión es automática.

---

## Controles de reproducción

| Control | Acción | Función |
|---|---|---|
| Encoder — girar derecha | Subir volumen | Incrementa el volumen del sistema |
| Encoder — girar izquierda | Bajar volumen | Decrementa el volumen del sistema |
| Encoder — presionar | Play/Pause | Reproduce o pausa la reproducción |
| Botón PREV | Presionar | Retrocede a la pista anterior |
| Botón NEXT | Presionar | Avanza a la siguiente pista |
| Botón MUTE | Presionar | Silencia o activa el audio |

---

## Indicadores visuales

### LED azul — estado Bluetooth

| Estado del LED | Significado |
|---|---|
| Parpadeo rápido | Sin conexión — buscando dispositivo |
| Apagado | Conexión Bluetooth activa |

### LED rojo — estado de batería

| Estado del LED | Significado |
|---|---|
| Apagado | Batería OK — nivel suficiente |
| Parpadeo lento | Batería baja — recargar pronto |
| Parpadeo rápido | Batería crítica — recargar inmediatamente |

---

## Carga de batería

1. Conectar un cable USB-C al puerto **USB** ubicado en la parte inferior
   derecha del dispositivo.
2. Conectar el otro extremo a un cargador USB estándar o puerto USB de
   computadora.
3. El dispositivo puede seguir en uso durante la carga.
4. Desconectar el cable cuando la batería esté cargada.

> El módulo TP4056 incluye protección contra sobrecarga — no hay riesgo de
> dañar la batería si se deja conectado.

---

## Solución de problemas

| Problema | Posible causa | Solución |
|---|---|---|
| LED azul no enciende | Dispositivo apagado o batería descargada | Verificar interruptor SW y cargar batería |
| No aparece en la lista de Bluetooth | Dispositivo fuera de rango o apagado | Acercar el dispositivo y verificar que está encendido |
| Comandos no responden | Sin conexión Bluetooth | Verificar que el LED azul está apagado — si parpadea, reconectar |
| LED rojo parpadea rápido | Batería crítica | Cargar el dispositivo inmediatamente |
| Volumen cambia muy rápido | Normal — girar el encoder más despacio | Girar el encoder lentamente para ajuste fino |

---

*Proyecto: Controlador Multimedia Bluetooth — Sistemas Embebidos II*
*Universidad Católica Boliviana — Ingeniería Mecatrónica*

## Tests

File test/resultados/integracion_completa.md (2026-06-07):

# Resultados — Integración completa

## Configuración de prueba

| Parámetro | Valor |
|---|---|
| Fecha | Mayo 2026 |
| Firmware | v0.1.0 |
| Dispositivo objetivo | Ubuntu 24.04 LTS con Bluetooth integrado |
| Aplicación | Spotify |

---

## Resultados por comando

| Comando | Control físico | Resultado |
|---|---|---|
| Play/Pause | Encoder — presionar | ✓ Funciona |
| Siguiente pista | Botón 1 | ✓ Funciona |
| Pista anterior | Botón 2 | ✓ Funciona |
| Subir volumen | Encoder — girar derecha | ✓ Funciona |
| Bajar volumen | Encoder — girar izquierda | ✓ Funciona |
| Mute/Unmute | Botón 3 | ✓ Funciona |

---

## Estabilidad

| Métrica | Resultado |
|---|---|
| Duración de sesión continua | ~30 minutos |
| Desconexiones espontáneas | Ninguna |
| Reconexión tras desconexión | Manual desde Configuración → Bluetooth |

---

## Observaciones

- Ubuntu desconecta el dispositivo tras período de inactividad HID — comportamiento normal del sistema operativo.
- La reconexión manual desde Configuración → Bluetooth funciona correctamente sin necesidad de re-emparejar.

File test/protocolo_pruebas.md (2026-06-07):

# Protocolo de pruebas formales — Controlador Multimedia Bluetooth v1.0

Define las pruebas a realizar para validación funcional del sistema completo.

---

## Configuración base

| Parámetro | Valor |
|---|---|
| Firmware | v1.0.0 |
| Dispositivo objetivo | Ubuntu 24.04 LTS con Bluetooth integrado |
| Batería | Li-ion 18650 3.7V 2600mAh cargada completamente |

---

## Prueba 1 — Alcance BLE

**Objetivo:** determinar el rango operativo del enlace Bluetooth en condiciones reales.

**Procedimiento:**
1. Conectar el dispositivo y establecer conexión BLE.
2. Ejecutar un comando de prueba (Play/Pause) en cada rango.
3. Registrar si el comando se ejecuta correctamente.
4. Repetir con y sin obstáculos entre el dispositivo y la computadora.

**Rangos evaluados:**

| Rango | Condición | Resultado |
|---|---|---|
| Corto (< 5m) | Sin obstáculos | — |
| Medio (5–10m) | Sin obstáculos | — |
| Largo (> 10m) | Sin obstáculos | — |
| Corto (< 5m) | Con obstáculos (paredes/puertas) | — |
| Medio (5–10m) | Con obstáculos (paredes/puertas) | — |

**Métrica:** rango máximo operativo con y sin obstáculos.

---

## Prueba 2 — Latencia

**Objetivo:** evaluar el tiempo de respuesta entre activación del control y
ejecución de la acción en Ubuntu.

**Procedimiento:**
1. Conectar el monitor serie del ESP32.
2. Ejecutar cada comando 10 veces.
3. Registrar el timestamp del evento en el monitor serie.
4. Evaluar subjetivamente si el retardo es perceptible durante el uso normal.

**Comandos evaluados:**

| Comando | Evaluación subjetiva | Timestamp promedio (ms) |
|---|---|---|
| Play/Pause | — | — |
| Siguiente pista | — | — |
| Pista anterior | — | — |
| Subir volumen | — | — |
| Bajar volumen | — | — |
| Mute/Unmute | — | — |

**Métrica:** timestamp del firmware + evaluación cualitativa (perceptible / no perceptible).

---

## Prueba 3 — Autonomía de batería

**Objetivo:** medir el tiempo de operación continua con batería completamente cargada.

**Procedimiento:**
1. Cargar la batería completamente.
2. Encender el dispositivo y establecer conexión BLE.
3. Ejecutar comandos aproximadamente cada 5 minutos simulando uso normal.
4. Registrar hora de inicio y hora en que el dispositivo deja de funcionar.

**Registro:**

| Parámetro | Valor |
|---|---|
| Hora de inicio | — |
| Hora de fin | — |
| Duración total | — |
| Nivel de batería al inicio | 100% |

**Métrica:** horas de operación continua en uso normal.

---

## Prueba 4 — Confiabilidad

**Objetivo:** verificar que los comandos se ejecutan correctamente de manera
consistente bajo uso repetido.

**Procedimiento:**
1. Conectar el dispositivo y establecer conexión BLE.
2. Ejecutar cada comando 50 veces consecutivas.
3. Registrar cuántos se ejecutaron correctamente en Ubuntu.

**Resultados:**

| Comando | Ejecutados | Correctos | Fallidos | Tasa de éxito |
|---|---|---|---|---|
| Play/Pause | 50 | — | — | — |
| Siguiente pista | 50 | — | — | — |
| Pista anterior | 50 | — | — | — |
| Subir volumen | 50 | — | — | — |
| Bajar volumen | 50 | — | — | — |
| Mute/Unmute | 50 | — | — | — |
| **Total** | **300** | — | — | — |

**Métrica:** porcentaje de éxito por comando y global.

---

## Prueba 5 — Compatibilidad

**Objetivo:** verificar funcionamiento con distintas aplicaciones de reproducción.

**Procedimiento:**
1. Conectar el dispositivo y establecer conexión BLE.
2. Probar los 6 comandos con cada aplicación.
3. Registrar cuáles comandos responden correctamente.

**Resultados:**

| Comando | Spotify | VLC | — |
|---|---|-----|---|
| Play/Pause | — | — | — |
| Siguiente pista | — | — | — |
| Pista anterior | — | — | — |
| Subir volumen | — | — | — |
| Bajar volumen | — | — | — |
| Mute/Unmute | — | — | — |

> Completar la tercera columna con la aplicación adicional elegida al momento
> de ejecutar las pruebas.

**Métrica:** tabla de compatibilidad por aplicación.

---

*Proyecto: Controlador Multimedia Bluetooth — Sistemas Embebidos II*
*Universidad Católica Boliviana — Ingeniería Mecatrónica*

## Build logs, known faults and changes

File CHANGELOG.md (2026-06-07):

# Registro de cambios

Todos los cambios notables de este proyecto se documentan en este archivo.
Formato basado en [Keep a Changelog](https://keepachangelog.com/es/1.0.0/).
Versionado basado en [SemVer](https://semver.org/lang/es/).

---

## [Sin publicar]

### Firmware
- Validación funcional con batería real pendiente

### Hardware
- Impresión 3D de carcasa pendiente

### Documentación
- Documentación técnica del sistema pendiente

### Pruebas
- Pruebas formales pendientes de ejecución

---

## [0.3.0] — 2026-06-07

### Hardware
- Fabricación física del PCB completada
- Diseño 3D de carcasa completado

### Documentación
- Lista de materiales con especificaciones y precios a junio 2026
- Manual de usuario con disposición de controles e indicadores visuales
- Decisiones de diseño PCB con justificación técnica
- Protocolo de pruebas formales definido

### Repositorio
- Reestructuración de carpetas hardware/ — kicad/ y exportaciones/
- Roadmap reestructurado por áreas de trabajo
- pines.md actualizado con nueva asignación de LEDs y correcciones técnicas

---

## [0.2.0] — 2026-06-07

### Firmware
- Gestión de energía: lectura ADC batería con promediado de 16 muestras y calibración line fitting
- Gestión de energía: modem sleep via esp_pm con escalado dinámico de frecuencia CPU (40–160MHz)
- Indicadores LED integrados con estado BLE y nivel de batería
- Refactorización de arquitectura: centralización de configuración en config.h
- Renombrado EVT_SILENCIAR → EVT_MUTE_UNMUTE para reflejar función toggle
- Eliminación de input_task — command_task lee directamente de la cola de entrada
- Constantes de comportamiento movidas a headers públicos
- Watchpoints del encoder ajustados de ±2 a ±4 — un evento por detente físico completo
- Debouncing de botones ajustado a 150ms

### Hardware
- Reasignación de LEDs: GPIO26/GPIO27 → GPIO32/GPIO33 para facilitar ruteo PCB
- Esquemático actualizado con nueva asignación de pines
- Exportación de Gerbers

### Documentación
- Reestructuración de carpetas hardware/ — kicad/ y exportaciones/
- Decisiones de diseño PCB documentadas en docs/diseno_pcb.md
- Roadmap reestructurado por áreas de trabajo
- pines.md actualizado con nueva asignación de LEDs y correcciones técnicas

---

## [0.1.0] — 2026-05-31

Primera versión funcional del proyecto. MVP validado en hardware físico.
Los 6 comandos multimedia operan end-to-end desde el hardware hasta Ubuntu via BLE HID.

### Firmware
- Integración completa validada: Play/Pause, Siguiente, Anterior, Volumen +/−, Mute/Unmute
- Perfil HID Consumer Control sobre BLE (NimBLE) con reportes GATT
- Device Information Service con PnP ID (Espressif)
- Stack NimBLE con advertising y reconexión automática ante desconexión
- Máquina de estados: SYS_ADVERTISING, SYS_CONNECTED
- Acceso thread-safe al estado del sistema mediante mutex FreeRTOS
- Driver de botones: ISR con debouncing por timestamp en GPIO22, GPIO23, GPIO25, GPIO21
- Driver de encoder EC11: periférico PCNT con filtro de glitches (10µs), watch points en ±4
- Control de LEDs con cuatro patrones via esp_timer: apagado, encendido, parpadeo rápido (200ms), parpadeo lento (1000ms)
- NVS Flash inicializado en app_main para persistencia del stack Bluetooth
- Abstracción HID encapsulada en el módulo comunicacion_bt

### Hardware
- Esquemático KiCad completo con cadena de potencia: batería → TP4056 → MT3608 → AMS1117-3.3V → ESP32
- ERC sin errores
- Huellas asignadas a todos los componentes
- Modelos 3D asignados a todos los componentes

### Documentación
- README con descripción, requisitos e instrucciones
- Asignación de pines con justificación técnica y restricciones del ESP32
- Resultados de prueba de integración completa — sesión continua de 30+ minutos sin desconexiones

---

*Formato basado en [Keep a Changelog](https://keepachangelog.com/es/1.0.0/)*
*Versionado basado en [SemVer](https://semver.org/lang/es/)*

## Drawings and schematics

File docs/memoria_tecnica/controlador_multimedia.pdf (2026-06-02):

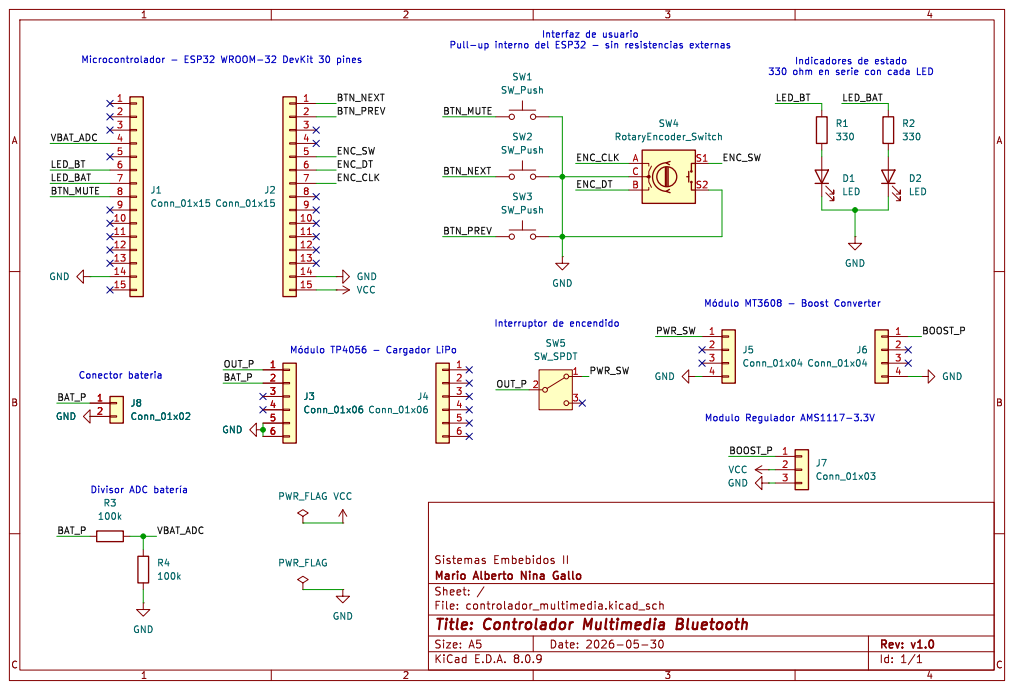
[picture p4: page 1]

330 ohm en serie con cada LED

Id: 1/1 Title: Controlador Multimedia Bluetooth

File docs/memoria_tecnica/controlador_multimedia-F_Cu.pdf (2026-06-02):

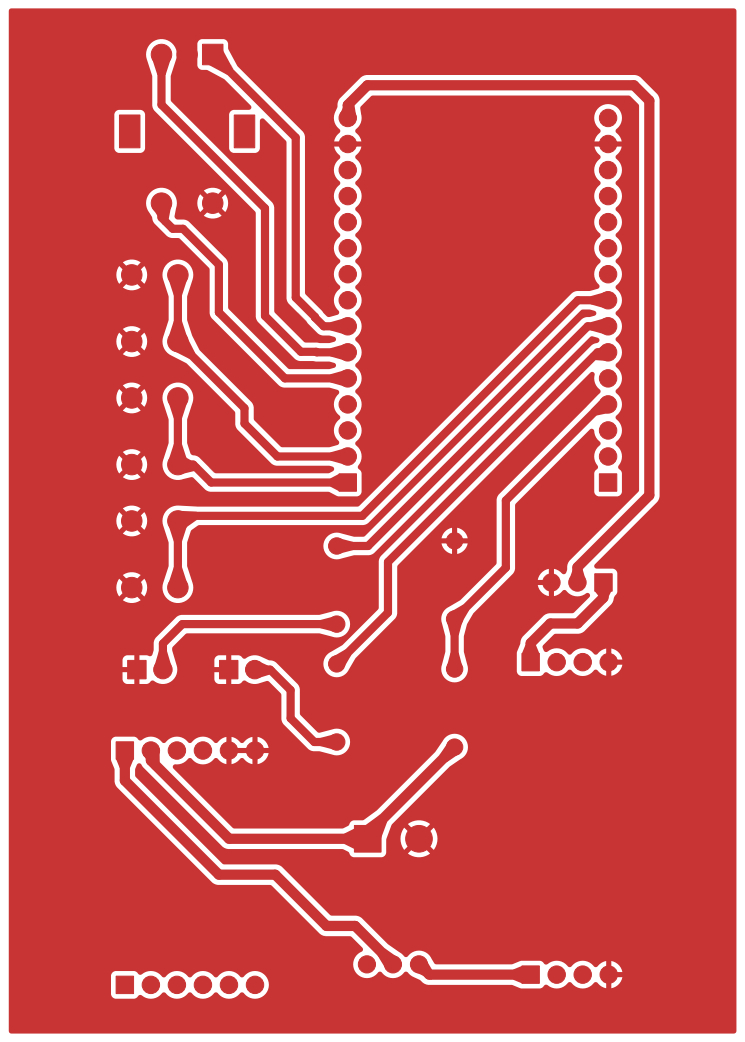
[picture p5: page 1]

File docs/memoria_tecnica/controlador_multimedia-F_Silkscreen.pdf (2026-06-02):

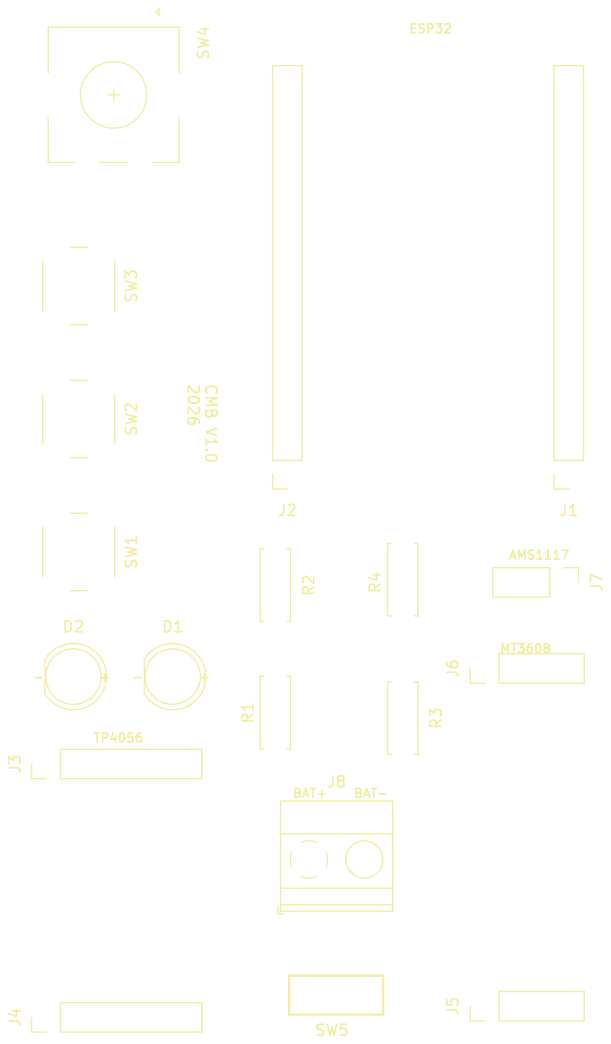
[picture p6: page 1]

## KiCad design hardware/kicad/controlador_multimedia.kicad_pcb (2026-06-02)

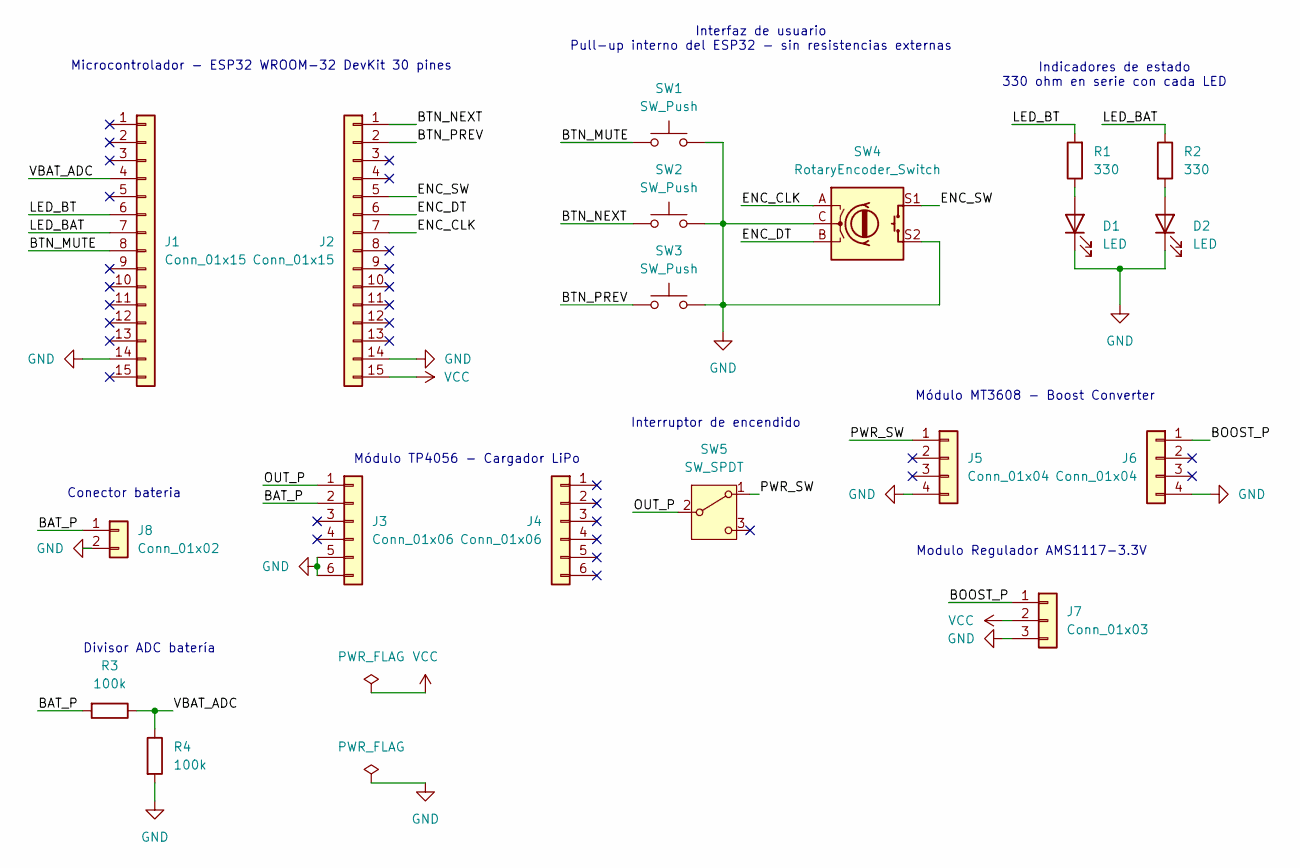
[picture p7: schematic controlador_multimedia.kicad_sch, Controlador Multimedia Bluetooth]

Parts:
D1, D2: LED; LED_D5.0mm
J1, J2: Conn_01x15; PinSocket_1x15_P2.54mm_Vertical
J3, J4: Conn_01x06; PinHeader_1x06_P2.54mm_Vertical
J5, J6: Conn_01x04; PinHeader_1x04_P2.54mm_Vertical
J7: Conn_01x03; PinHeader_1x03_P2.54mm_Vertical
J8: Conn_01x02; TerminalBlock_Phoenix_MKDS-1,5-2_1x02_P5.00mm_Horizontal
R1, R2: 330; R_Axial_DIN0207_L6.3mm_D2.5mm_P7.62mm_Horizontal
R3, R4: 100k; R_Axial_DIN0207_L6.3mm_D2.5mm_P7.62mm_Horizontal
SW1, SW2, SW3: SW_Push; SW_PUSH_6mm_H5mm
SW4: RotaryEncoder_Switch; RotaryEncoder_Alps_EC11E-Switch_Vertical_H20mm
SW5: SW_SPDT; Schiebeschalter_SS-12D00

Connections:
/BAT_P: J3.2, J8.1, R3.2
/BOOST_P: J6.1, J7.1
/BTN_MUTE: J1.8, SW1.1
/BTN_NEXT: J2.1, SW2.1
/BTN_PREV: J2.2, SW3.1
/ENC_CLK: J2.7, SW4.A
/ENC_DT: J2.6, SW4.B
/ENC_SW: J2.5, SW4.S1
/LED_BAT: J1.7, R2.1
/LED_BT: J1.6, R1.2
/OUT_P: J3.1, SW5.2 (B)
/PWR_SW: J5.1, SW5.1 (A)
/VBAT_ADC: J1.4, R3.1, R4.1
GND: D1.1 (K), D2.1 (K), J1.14, J2.14, J3.5, J3.6, J5.4, J6.4, J7.3, J8.2, R4.2, SW1.2, SW2.2, SW3.2, SW4.C, SW4.S2
unnamed: D1.2 (A), R1.1
unnamed: D2.2 (A), R2.2
VCC: J2.15, J7.2

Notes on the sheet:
Módulo TP4056 - Cargador LiPo
Módulo MT3608 - Boost Converter
Interfaz de usuario Pull-up interno del ESP32 - sin resistencias externas
Indicadores de estado 330 ohm en serie con cada LED
Microcontrolador - ESP32 WROOM-32 DevKit 30 pines
Divisor ADC batería
Conector bateria
Modulo Regulador AMS1117-3.3V
Interruptor de encendido

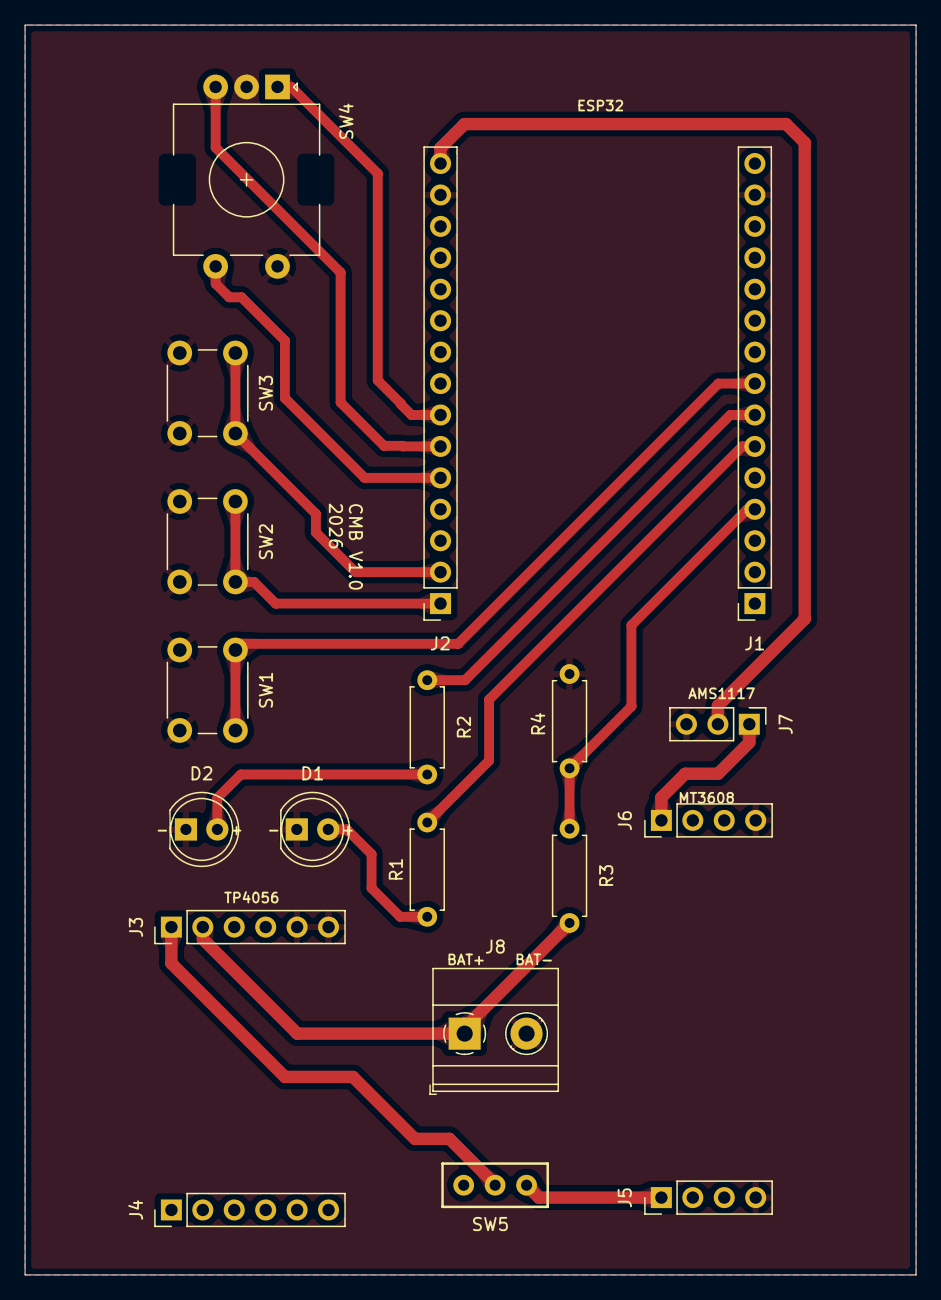
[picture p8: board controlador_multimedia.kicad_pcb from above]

Board: 2 copper layers, 72.0 x 101.0 mm, 19 parts (0 on the bottom side), 17 nets.

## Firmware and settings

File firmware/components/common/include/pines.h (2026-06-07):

/**
 * @file pines.h
 * @brief Mapa centralizado de asignación de pines GPIO del sistema.
 */

#pragma once

/* Botones */
#define PIN_BOTON_NEXT        22  /**< Siguiente pista    */
#define PIN_BOTON_PREV        23  /**< Pista anterior     */
#define PIN_BOTON_MUTE_UNMUTE 25  /**< Mute/Unmute        */

/* Encoder rotativo EC11 */
#define PIN_ENCODER_CLK  18  /**< Señal de reloj          */
#define PIN_ENCODER_DT   19  /**< Señal de datos          */
#define PIN_ENCODER_SW   21  /**< Pulsador del encoder    */

/* LEDs de estado */
#define PIN_LED_AZUL     32  /**< Estado Bluetooth        */
#define PIN_LED_ROJO     33	  /**< Estado batería          */

/* ADC */
#define PIN_ADC_BATERIA  34  /**< GPIO del divisor resistivo de batería — ADC1_CH6 */

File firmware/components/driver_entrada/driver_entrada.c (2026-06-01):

/**
 * @file driver_entrada.c
 * @brief Implementación del driver de entrada — coordina botones y encoder.
 */

#include "driver_entrada.h"
#include "botones.h"
#include "encoder.h"
#include "esp_log.h"
#include "driver/gpio.h"

static const char *TAG = "driver_entrada";

static QueueHandle_t cola_eventos = NULL;

void driver_entrada_init(void)
{
    cola_eventos = xQueueCreate(COLA_ENTRADA_TAM, sizeof(evento_entrada_t));
    if (cola_eventos == NULL) {
        ESP_LOGE(TAG, "Error al crear cola de eventos");
        return;
    }

    /* ISR_FLAGS_DEFAULT: sin flags especiales, prioridad estándar */
    ESP_ERROR_CHECK(gpio_install_isr_service(ISR_FLAGS_DEFAULT));

    botones_init(cola_eventos);
    encoder_init(cola_eventos);

    ESP_LOGI(TAG, "Driver de entrada inicializado");
}

QueueHandle_t driver_entrada_get_queue(void)
{
    return cola_eventos;
}

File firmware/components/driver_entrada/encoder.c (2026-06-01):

/**
 * @file encoder.c
 * @brief Implementación del driver de encoder rotativo EC11 mediante PCNT.
 */

#include "encoder.h"
#include "driver_entrada.h"
#include "pines.h"
#include "esp_log.h"
#include "esp_timer.h"
#include "driver/gpio.h"
#include "driver/pulse_cnt.h"

static const char *TAG = "encoder";

static pcnt_unit_handle_t pcnt_unit = NULL;

/**
 * @brief Callback del PCNT — dispara al alcanzar un watch point.
 *
 * ultimo_valor y ultimo_tiempo son estáticos para mantener estado
 * entre llamadas sucesivas del callback.
 */
static bool callback_pcnt(pcnt_unit_handle_t unit,
                           const pcnt_watch_event_data_t *edata,
                           void *user_ctx)
{
    (void)unit;

    static volatile int     ultimo_valor  = 0;
    static volatile int64_t ultimo_tiempo = 0;

    int64_t ahora = esp_timer_get_time();
    int     valor = edata->watch_point_value;

    if ((valor != ultimo_valor) && ((ahora - ultimo_tiempo) < ENCODER_DEBOUNCE_US)) {
        return pdFALSE;
    }

    ultimo_valor  = valor;
    ultimo_tiempo = ahora;

    QueueHandle_t    cola                 = (QueueHandle_t)user_ctx;
    evento_entrada_t evento               = (valor > 0) ? EVT_VOL_SUBIR : EVT_VOL_BAJAR;
    BaseType_t       debe_cambiar_contexto = pdFALSE;

    xQueueSendFromISR(cola, &evento, &debe_cambiar_contexto);
    return (debe_cambiar_contexto == pdTRUE);
}

void encoder_init(QueueHandle_t cola)
{
    ESP_ERROR_CHECK(gpio_set_pull_mode(PIN_ENCODER_CLK, GPIO_PULLUP_ONLY));
    ESP_ERROR_CHECK(gpio_set_pull_mode(PIN_ENCODER_DT,  GPIO_PULLUP_ONLY));

    pcnt_unit_config_t unit_config = {
        .high_limit =  ENCODER_WATCHPOINT,
        .low_limit  = -ENCODER_WATCHPOINT,
    };
    ESP_ERROR_CHECK(pcnt_new_unit(&unit_config, &pcnt_unit));

    pcnt_glitch_filter_config_t filter_config = {
        .max_glitch_ns = ENCODER_FILTRO_GLITCH_NS,
    };
    ESP_ERROR_CHECK(pcnt_unit_set_glitch_filter(pcnt_unit, &filter_config));

    pcnt_chan_config_t chan_a_config = {
        .edge_gpio_num  = PIN_ENCODER_CLK,
        .level_gpio_num = PIN_ENCODER_DT,
    };
    pcnt_channel_handle_t chan_a = NULL;
    ESP_ERROR_CHECK(pcnt_new_channel(pcnt_unit, &chan_a_config, &chan_a));

    pcnt_chan_config_t chan_b_config = {
        .edge_gpio_num  = PIN_ENCODER_DT,
        .level_gpio_num = PIN_ENCODER_CLK,
    };
    pcnt_channel_handle_t chan_b = NULL;
    ESP_ERROR_CHECK(pcnt_new_channel(pcnt_unit, &chan_b_config, &chan_b));

    ESP_ERROR_CHECK(pcnt_channel_set_edge_action(chan_a,
        PCNT_CHANNEL_EDGE_ACTION_DECREASE,
        PCNT_CHANNEL_EDGE_ACTION_INCREASE));
    ESP_ERROR_CHECK(pcnt_channel_set_level_action(chan_a,
        PCNT_CHANNEL_LEVEL_ACTION_KEEP,
        PCNT_CHANNEL_LEVEL_ACTION_INVERSE));

    ESP_ERROR_CHECK(pcnt_channel_set_edge_action(chan_b,
        PCNT_CHANNEL_EDGE_ACTION_INCREASE,
        PCNT_CHANNEL_EDGE_ACTION_DECREASE));
    ESP_ERROR_CHECK(pcnt_channel_set_level_action(chan_b,
        PCNT_CHANNEL_LEVEL_ACTION_KEEP,
        PCNT_CHANNEL_LEVEL_ACTION_INVERSE));

    ESP_ERROR_CHECK(pcnt_unit_add_watch_point(pcnt_unit,  ENCODER_WATCHPOINT));
    ESP_ERROR_CHECK(pcnt_unit_add_watch_point(pcnt_unit, -ENCODER_WATCHPOINT));

    pcnt_event_callbacks_t cbs = {
        .on_reach = callback_pcnt,
    };
    ESP_ERROR_CHECK(pcnt_unit_register_event_callbacks(pcnt_unit, &cbs, cola));

    ESP_ERROR_CHECK(pcnt_unit_enable(pcnt_unit));
    ESP_ERROR_CHECK(pcnt_unit_clear_count(pcnt_unit));
    ESP_ERROR_CHECK(pcnt_unit_start(pcnt_unit));

    ESP_LOGI(TAG, "Encoder PCNT inicializado — GPIO%d GPIO%d",
             PIN_ENCODER_CLK, PIN_ENCODER_DT);
}

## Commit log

2026-05-17 feat: crear proyecto ESP-IDF con target esp32
2026-05-17 hardware: iniciar esquemático con headers ESP32 DevKit
    [controlador_multimedia.kicad_pcb, controlador_multimedia.kicad_sch]
2026-05-17 chore: excluir archivos temporales de KiCad del repositorio
2026-05-17 docs: agregar versiones del entorno de desarrollo
2026-05-17 feat: crear estructura de 4 componentes ESP-IDF
2026-05-17 chore: registrar carpeta de componentes en CMakeLists raíz
2026-05-17 docs: agregar tabla de pines y roadmap del proyecto
2026-05-17 feat: implementar driver_entrada con botones e interrupciones GPIO
2026-05-17 feat: separar driver_entrada en botones.c y encoder.c con PCNT
2026-05-17 feat: implementar máquina de estados y tareas input_task y command_task
2026-05-17 docs: agregar pines.md con asignación completa y restricciones del ESP32
2026-05-17 hardware: agregar botones, encoder y net labels al esquemático KiCad
    [controlador_multimedia.kicad_sch]
2026-05-17 chore: eliminar archivo de autoguardado de KiCad
2026-05-17 chore: agregar archivo de autoguardado de KiCad a gitignore
2026-05-17 feat: implementar stack NimBLE con advertising y callbacks de conexión
2026-05-30 feat: agregar Device Information Service y control de suscripcion HID
2026-05-30 test: registrar resultados de pruebas de integración Fase 9
2026-05-30 hardware: completar esquemático con cadena de potencia y ERC sin errores
    [controlador_multimedia.kicad_sch]
2026-05-31 hardware: asignar huellas y modelos 3D a todos los componentes
    [controlador_multimedia.kicad_pcb, controlador_multimedia.kicad_sch]
2026-05-31 fix: corregir workflow CI para usar esp-idf-ci-action oficial
2026-05-31 refactor: centralizar pines en common/pines.h
    [controlador_multimedia.kicad_pcb, controlador_multimedia.kicad_sch]
2026-05-31 feat: implementar gestion_energia con ADC batería y power_task
2026-05-31 feat: integrar LEDs con estado BT y nivel batería
2026-05-31 refactor: auditoría de código — limpieza general
2026-05-31 feat: implementar modem sleep mediante esp_pm para reducir consumo BLE
2026-06-01 refactor: reorganizar arquitectura — config.h, buenas prácticas y limpieza general
2026-06-02 hardware: agregar diseño PCB v1.0 con ruteo completo, plano GND y Gerbers
    [controlador_multimedia.kicad_pcb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]
2026-06-07 hardware: reasignar LEDs GPIO26/27 → GPIO32/33 para facilitar ruteo PCB
2026-06-07 hardware: reestructurar carpetas — kicad/ y exportaciones/
    [controlador_multimedia.kicad_pcb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]
2026-06-07 docs: agregar decisiones de diseño PCB v1.0
2026-06-07 docs: reestructurar roadmap por áreas de trabajo
2026-06-07 docs: actualizar CHANGELOG — corregir inconsistencias y agregar v0.2.0
2026-06-07 docs: actualizar README — hardware, estructura y firmware actualizados
2026-06-07 test: renombrar y actualizar resultados de integración completa
2026-06-07 docs: agregar lista de materiales con precios a junio 2026
2026-06-07 docs: agregar manual de usuario v1.0
2026-06-07 docs: corregir manual de usuario
2026-06-07 docs: corregir disposición de controles en manual de usuario
2026-06-07 test: agregar protocolo de pruebas formales
2026-06-07 docs: actualizar roadmap — PCB completa, manual y lista de materiales
